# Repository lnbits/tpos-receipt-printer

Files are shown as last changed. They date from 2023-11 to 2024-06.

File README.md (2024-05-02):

# LNbits TpoS Printer

This project features an ESP32 controlled thermal printer solution to print payment receipts as payments are made to the LNbits TPoS extension.

Buy a complete kit on the LNbits shop: https://shop.lnbits.com/product/lnbits-tpos-thermal-receipt-printer

The project is fully inspired by the [Coinos printer](https://github.com/coinos/coinos-printer) project.

## Parts

1. An ESP32. This project used an ESP32-C3 SuperMini but any ESP32 will do as long as you can smush it into an enclosure
1. A 58mm Embedded Thermal Printer with TTL interface

## Flash firmware to the ESP32-C3

You will need:

+ Visual Studio Code with the platformio extension installed
+ Your ESP32-C3 board
+ A USB-C cable.

1. Open VS Code and open the `firmware` directory that is in this repo. Platformio will initialise the project and load all required dependencies.
1. Copy the file config.h.example to config.h and edit the variables in the file to your own values:
1. Connect your ESP32 board to your computer using the USB-C cable
1. Click the Upload button (the right facing arrow in the footer of the VS code IDE)
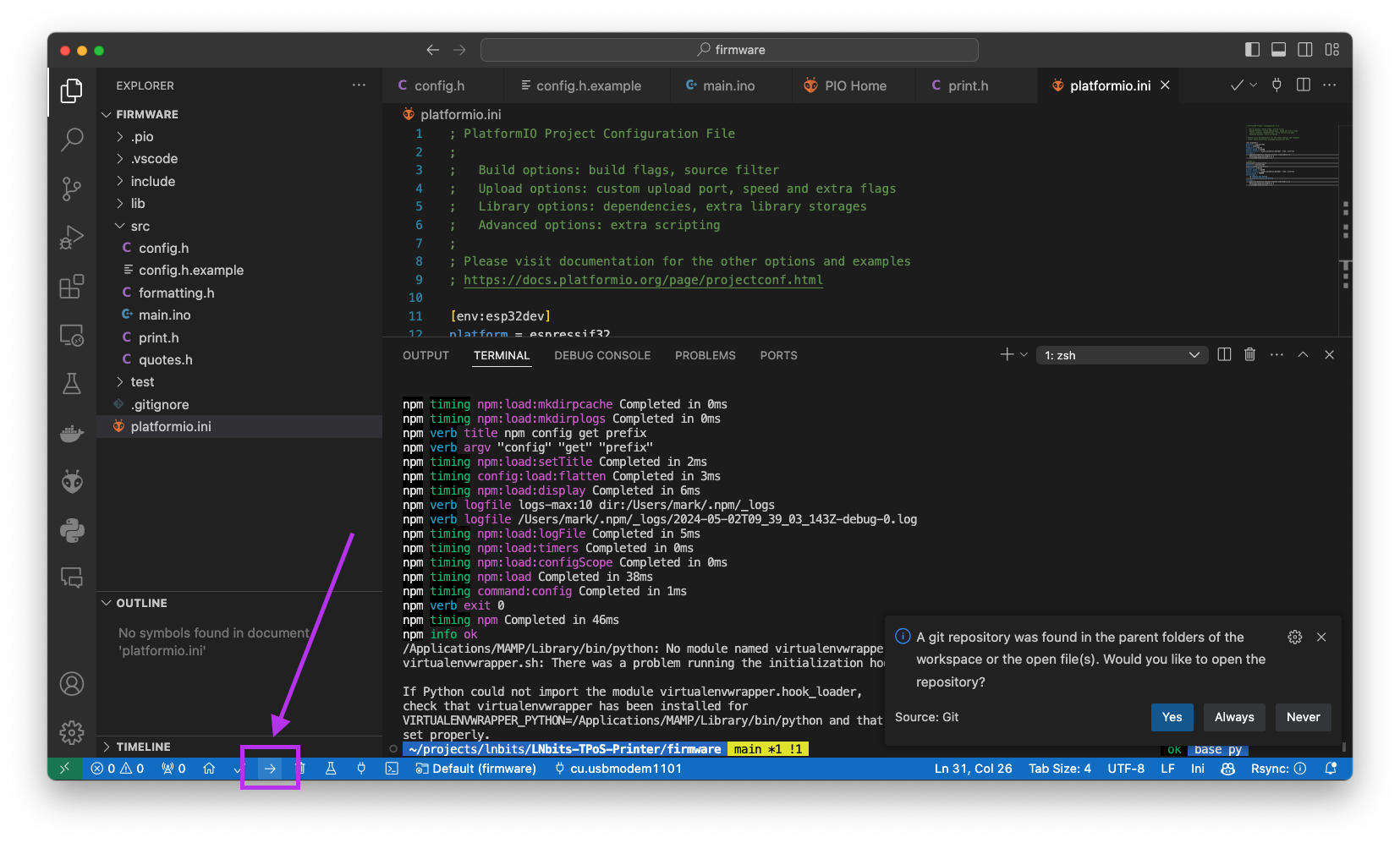
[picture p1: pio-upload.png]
pio upload

1. After flashing, your printer will connect to WiFi and print a short status message.

## Setup

Connect the printer to the ESP32 as follows.

You will probably need a seperate power supply for the printer as it needs ~ 1amp which an ESP32 struggles to provide.

1. Printer GND to ESP32 GND and power supply GND
1. Printer VCC to power supply 5v - 9v
1. Printer RX to ESP32 GPIO 21
1. Printer TX to ESP32 GPIO 2

You *may* be able to use the ESP32 5v pin to power the printer and I have had some success with this. However print quality is slightly degraded and speed is low. If you are going to do this, use a 5V power supply with at least 2 amps available. Wiring as follows:

1. Printer GND to ESP32 GND
1. Printer VCC to ESP32 5v
1. Printer RX to ESP32 GPIO 21
1. Printer TX to ESP32 GPIO 2

## Firmware

1. Copy config.h.example to config.h
1. Edit config.h to match your setup
1. Compile and upload to ESP32
1. Power on

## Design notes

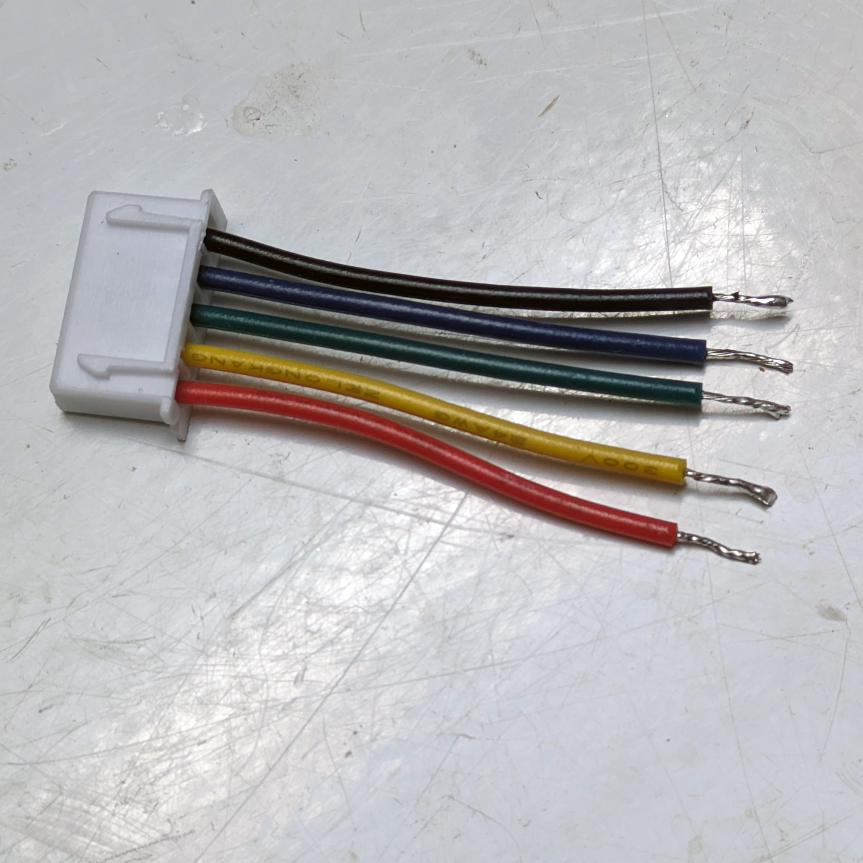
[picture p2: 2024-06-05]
docs/img/pcb 025.jpg

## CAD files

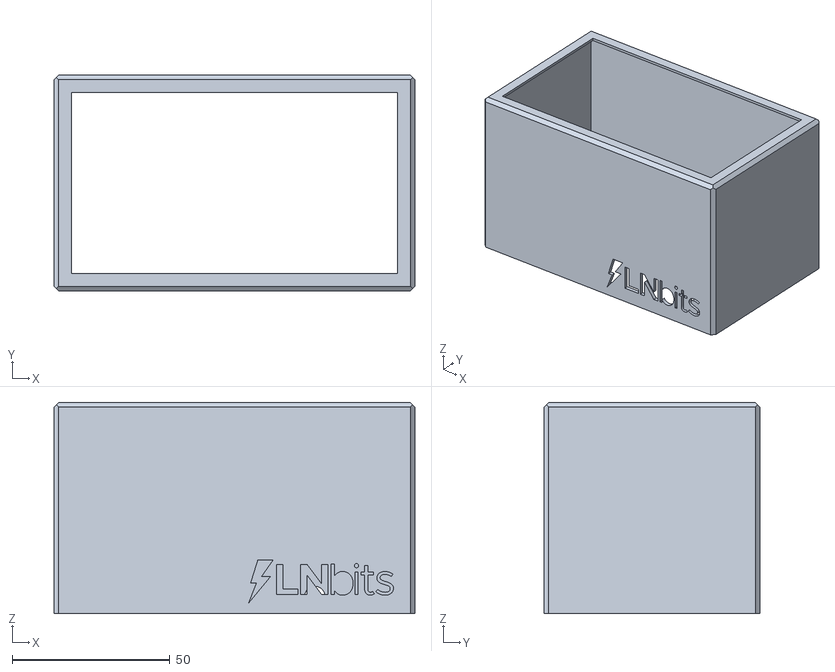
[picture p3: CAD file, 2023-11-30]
enclosure/Body.stl
114.5 x 68.5 x 67.0

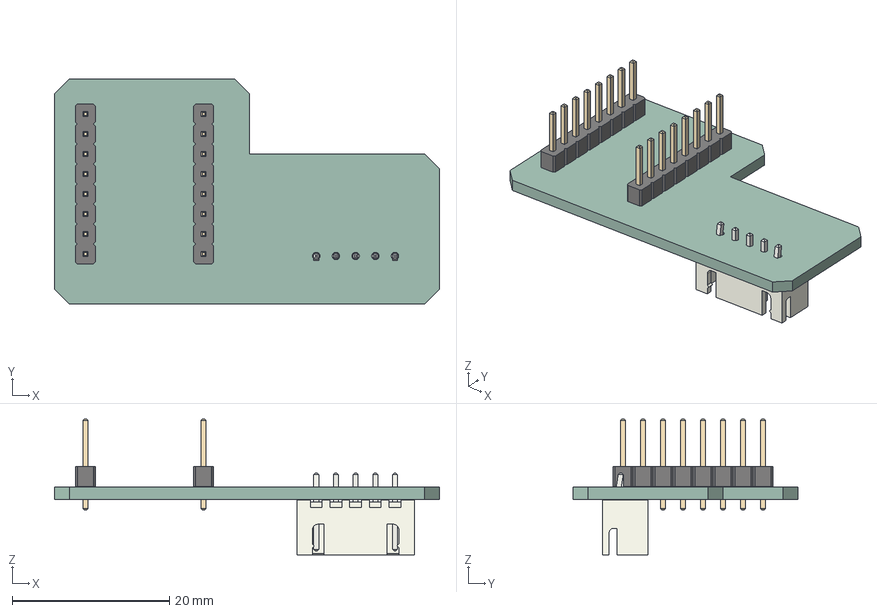
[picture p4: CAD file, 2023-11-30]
pcb/TPoS Printer/TPoS Printer.step
48.9 x 28.6 x 17.2 mm
TPoS Printer PCB

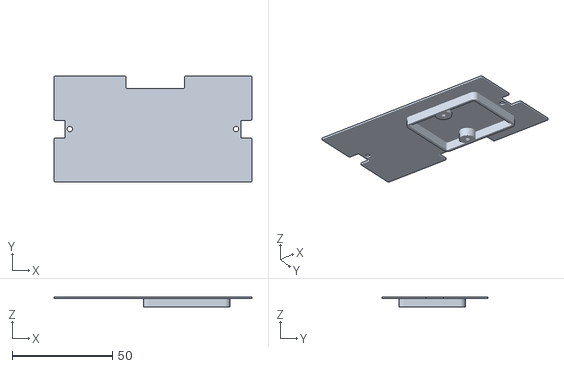
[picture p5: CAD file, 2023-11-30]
enclosure/Board mount square board.stl
98.6 x 52.7 x 5.00

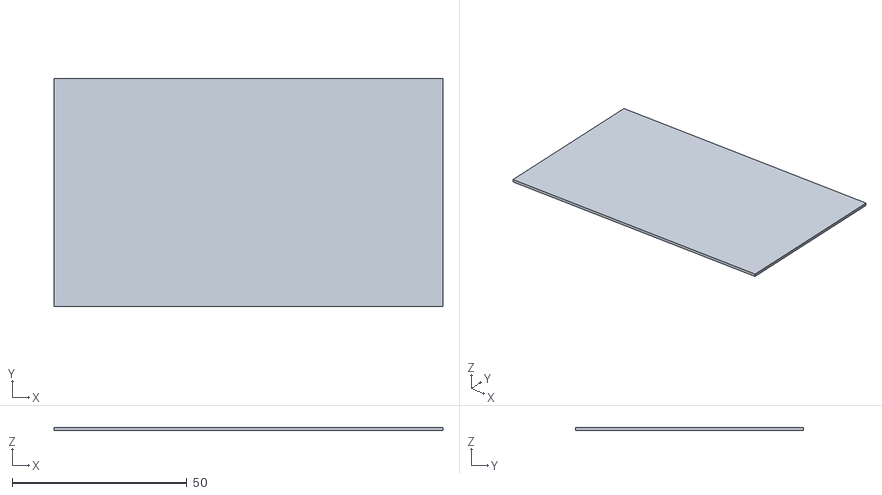
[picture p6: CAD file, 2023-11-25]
enclosure/Lid.stl
111.3 x 65.3 x 1.00

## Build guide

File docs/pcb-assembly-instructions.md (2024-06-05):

# LNbits TPoS Printer PCB Assembly Instructions

## Cable Preparation

Cut the printer cable to around 7cm in length. Don't cut it too short or it won't reach between the printer and the PCB.

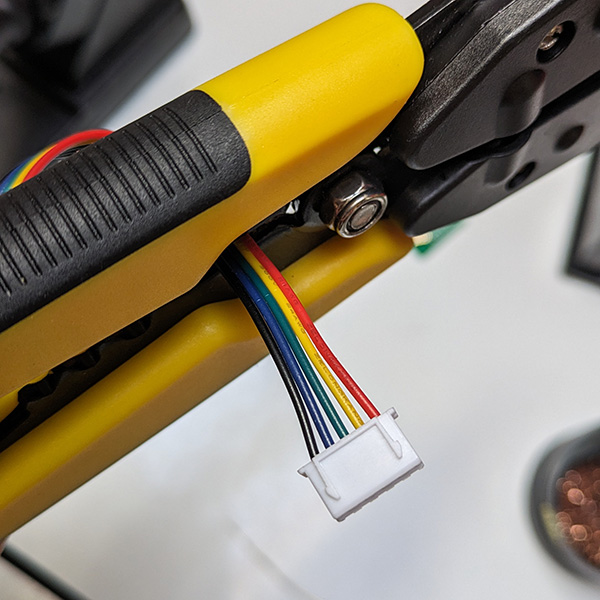
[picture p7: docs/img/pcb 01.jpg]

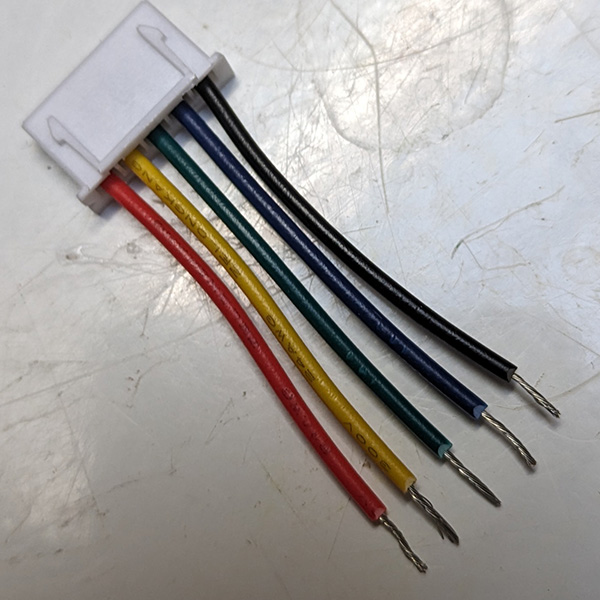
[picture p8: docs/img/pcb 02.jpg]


Tin the ends of the cut wires to make inserting them into the PCB easier

## ESP32 assembly

Solder the header pins to your ESP32 board

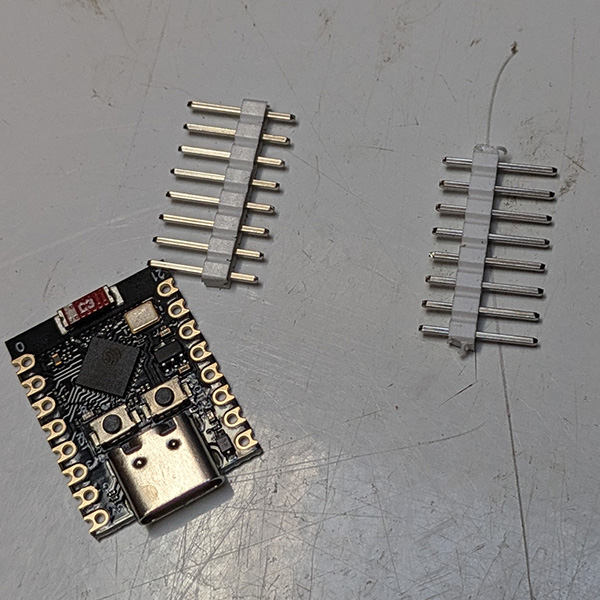
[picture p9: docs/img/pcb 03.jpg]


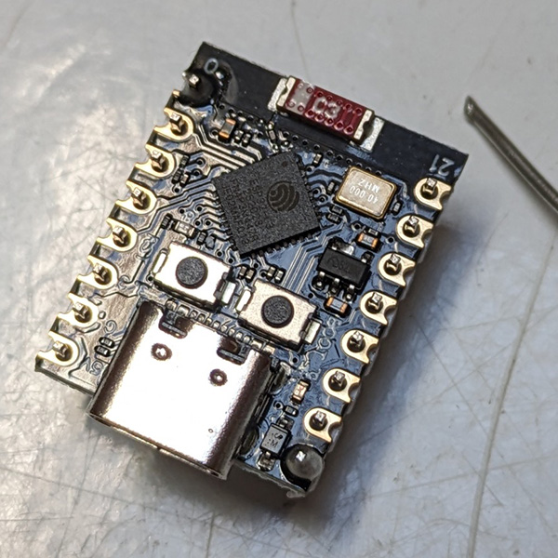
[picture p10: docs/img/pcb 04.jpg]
'Solder header pins'


Insert the ESP32 board into the PCB and solder pins 5V, GND, 2 AND 21

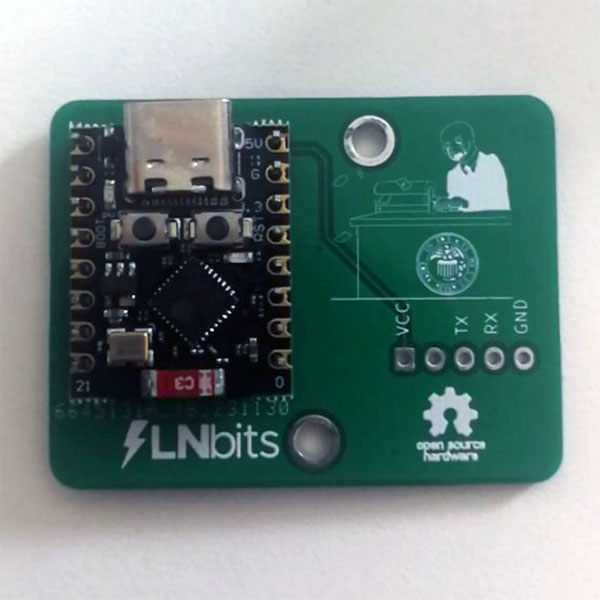
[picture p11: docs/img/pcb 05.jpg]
'Insert ESP32'


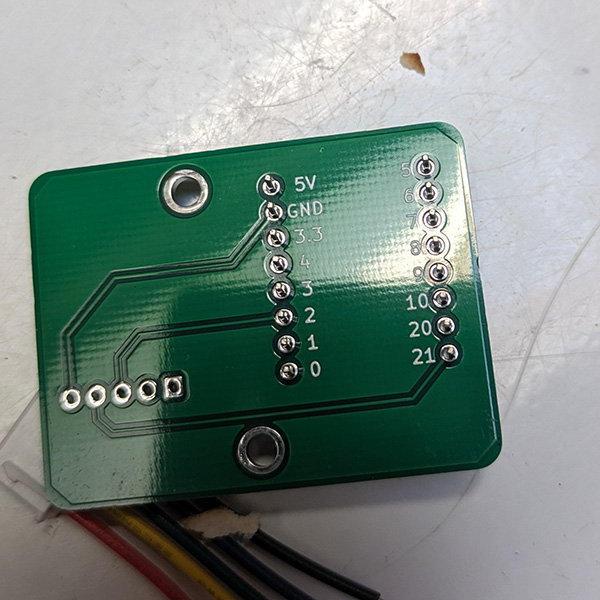
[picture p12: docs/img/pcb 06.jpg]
Rear of PCB

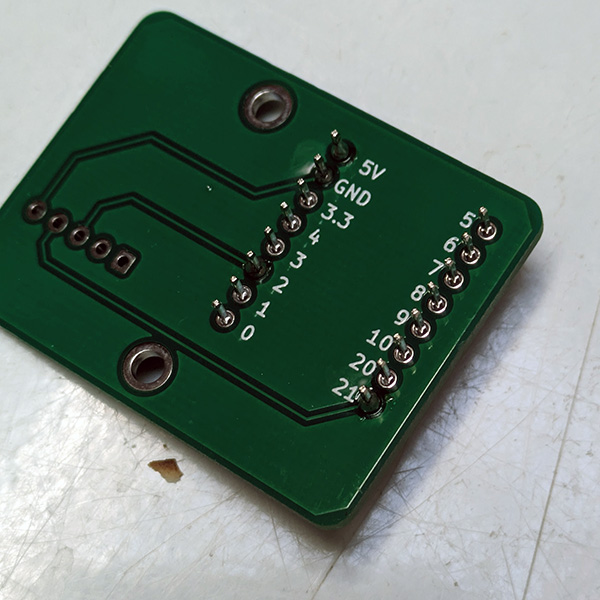
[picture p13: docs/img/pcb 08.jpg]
Soldered PCB


## Solder Cable to PCB

Insert the tinned wires into the PCB and solder them in place. Follow the photo below for the correct order.
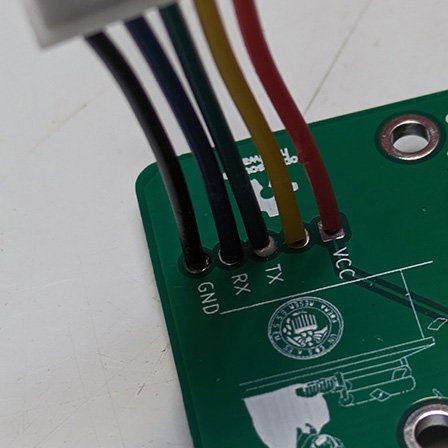
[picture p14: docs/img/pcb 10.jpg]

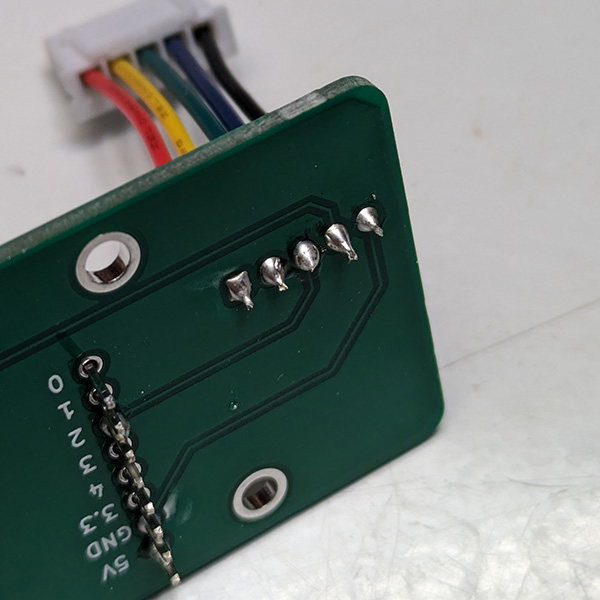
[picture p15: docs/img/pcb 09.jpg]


## Printer Assembly

Connect the printer cable to the printer and the PCB

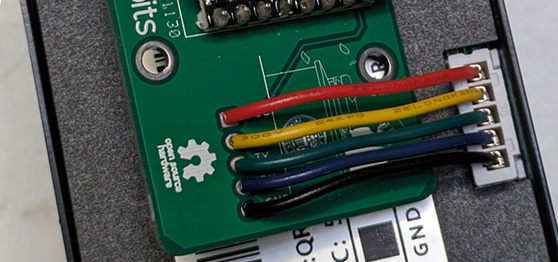
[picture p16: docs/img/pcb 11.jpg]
Printer cable


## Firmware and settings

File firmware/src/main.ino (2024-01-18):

#include "config.h"
#include "formatting.h"
#include "print.h"

#include <WiFi.h>
#include <SPIFFS.h>
#include <ArduinoJson.h>
#include "Adafruit_Thermal.h"
#include <WebSocketsClient.h>
#include <HTTPClient.h>


#define TX_PIN 21 // Arduino transmit  YELLOW WIRE  labeled RX on printer
#define RX_PIN 2 // Arduino receive   GREEN WIRE   labeled TX on printer

HardwareSerial mySerial(1); // Declare HardwareSerial obj first
Adafruit_Thermal printer(&mySerial);     // Pass addr to printer constructor

WebSocketsClient webSocket;

bool hasReceiptToPrint = false;

JsonVariant lastPayment;

String currentBlockHeight = "818,114";

/**
 * @brief Get the current block height from https://mempool.space/api/blocks/tip/height formatted nicely with commas
 * This URL returns one line of text e.g. "832123"
 * 
 * @param type 
 * @param payload 
 * @param length 
 */
String getBlockHeight() {
  HTTPClient http;
  http.begin("https://mempool.space/api/blocks/tip/height");
  int httpCode = http.GET();
  String payload = http.getString();
  http.end();

  if (httpCode == 200) {
    Serial.println("Block height: " + payload);
    // format with commas
    int blockHeight = payload.toInt();
    
    return formatNumber(blockHeight);
  } else {
    Serial.println("Error getting block height");
    return "";
  }
}

void webSocketEvent(WStype_t type, uint8_t * payload, size_t length) {
  switch(type) {
    case WStype_DISCONNECTED:
      Serial.printf("[WebSocket] Disconnected!\n");
      break;
    case WStype_CONNECTED:
      Serial.printf("[WebSocket] Connected to url: %s\n", payload);
      break;
    case WStype_TEXT:
      Serial.printf("[WebSocket] Received text: %s\n", payload);
      deserializeAndCompare(String((char *)payload));
      break;
  }
}

void connectToWifi() {
  // try to connect to WiFi for 10 seconds
  int i = 0;
  while (WiFi.status() != WL_CONNECTED && i < 10) {
    delay(1000);
    Serial.print(".");
    i++;
  }
  if (WiFi.status() == WL_CONNECTED) {
    Serial.println("Connected to WiFi");
    printConnectedToWifi();
    setupWebsocketConnection();
  } else {
    Serial.println("Failed to connect to WiFi");
    printFailedToConnectToWifi();
  }
}

void setupWebsocketConnection() {
  // clear websocket connection and reconnect if connected
  if (webSocket.isConnected()) {
    webSocket.disconnect();
  }
  webSocket.beginSSL(host, 443, "/api/v1/ws/" + String(walletId));
  webSocket.onEvent(webSocketEvent);
  webSocket.setReconnectInterval(5000); // Try to reconnect every 5 seconds
  webSocket.enableHeartbeat(5000, 3000, 2); // Send heartbeat every 15 seconds
}

void deserializeAndCompare(String json) {
  DynamicJsonDocument doc(4096);
  deserializeJson(doc, json);

  // Extract the 'payment' object from the received JSON
  JsonObject payment = doc["payment"];

  if (!payment.isNull()) {
    long time = payment["time"].as<long>();
    String paymentHash = payment["payment_hash"].as<String>();
    Serial.println("Payment time: " + String(time));
    String tag = payment["extra"]["tag"].as<String>();
    Serial.println("Tag: " + tag);
    String memo = payment["memo"].as<String>();
    Serial.println("Memo: " + memo);
    bool pending = payment["pending"].as<bool>();

    if (!pending && tag == "tpos" && memo.indexOf("tip") == -1) {
      Serial.println("New payment received!");
      lastPayment = payment;
      hasReceiptToPrint = true;
    }
  }
}

void setup() {
  delay(2000);
  Serial.begin(115200);
  Serial.println("Starting...");

  mySerial.begin(9600, SERIAL_8N1, RX_PIN, TX_PIN);
  printer.begin();
  printWelcomeReceipt();

  // printTestReceipt();
  
  // Connect to WiFi
  WiFi.begin(ssid, password);
  
  connectToWifi();
}

long lastWebsocketPingTime = 0;

long lastBlockHeightRetrieved = 0;

long lastWifiCheckTime = 0;

void loop() {
  webSocket.loop();

  // get block height every 1 minute
  if (millis() - lastBlockHeightRetrieved > 60000) {
    currentBlockHeight = getBlockHeight();
    lastBlockHeightRetrieved = millis();
  }

  // ping websocket every 10 seconds
  if (millis() - lastWebsocketPingTime > 10000) {
    webSocket.sendPing();
    lastWebsocketPingTime = millis();
  }
  
  printReceipt();

  // check wifi every 10 seconds and reconnect if needed
  if (millis() - lastWifiCheckTime > 10000) {
    if (WiFi.status() != WL_CONNECTED) {
      connectToWifi();
    }
    lastWifiCheckTime = millis();
  }
}

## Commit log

2023-11-21 Working. Connects to api and prints test lable
2023-11-21 wait for payment not pending before printing
2023-11-22 Updated readme with details for using quality USB power supply and powering printer from ESP32
2023-11-24 Disable test printing
2023-11-24 Use pin 21 instead of 15 for printer RX
2023-11-24 Added esp32 c3 build
2023-11-24 Added kicad designs and moved dirs
    [TPoS Printer-B_Cu.gbr, TPoS Printer-B_Mask.gbr, TPoS Printer-B_Paste.gbr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]
2023-11-25 Added enclosure
    [Body.stl, Lid.stl]
2023-11-30 Updated KiCad with square board and mounting holes
    [TPoS Printer.kicad_pcb, TPoS Printer.step]
2023-11-30 Updated pcb gerber files
    [TPoS Printer-B_Cu.gbr, TPoS Printer-B_Mask.gbr, TPoS Printer-B_Paste.gbr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]
2023-11-30 Updated 3d print files
    [Board mount square board.stl, Body.stl]
2023-11-30 Update 3d printed body stl
    [Body.stl]
2024-01-18 Various tweaks to receipt printing
2024-05-02 Added link to shop and printer interface details;
2024-06-05 Added PCB assembly instructions
2024-06-05 Update assembly images
